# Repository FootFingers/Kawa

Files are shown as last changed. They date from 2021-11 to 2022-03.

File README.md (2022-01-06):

# Kawa-HotSwap
## A 32 key 'fixed-split' pro-micro based keyboard with a 128x64 OLED display.

Forked from CoffeeBreakKeyboards [here](https://github.com/CoffeeBreakKeyboards/kawa) and updated to use Kailh Hotswap Sockets. 

A sandwich mount case was also created based on the original Kawa PCB footprint. The central section around the OLED and controller board is covered with a sheet of acrylic, and hardware has been added to provide wireless support. 

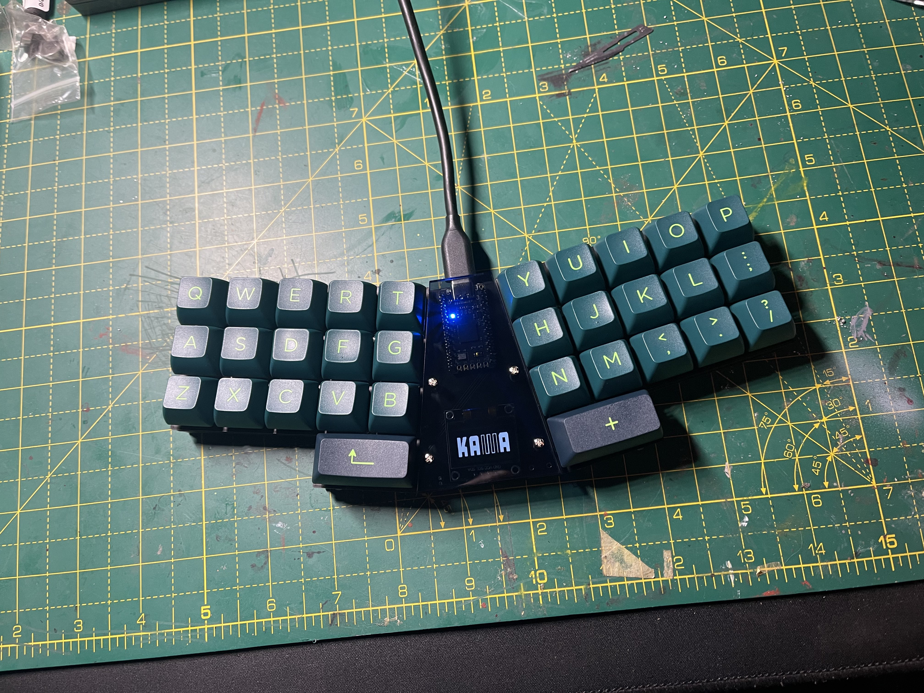
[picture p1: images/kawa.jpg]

*Pic of Kawa build courtesy of Porkus*

## Case
Plate files created:
 - Base Plate x1
 - Top Plate x2
 - Acrylic Centre Guard x1

## Firmware

Firmware files are available [here](https://github.com/sofubi/qmk_firmware/tree/kawa/rev0.1/keyboards/handwired/kawa)

Wireless firmware is still currently in development.

## Usage

Use these files at your own risk. This project is currently in development, and as such is likely to contain issues. 

## ToDo
- [ ] Wireless Firmware
- [ ] Build Guide
- [x] PCB updated to use hotswap sockets
- [x] Sandwich Mount Case + Acrylic Component Cover

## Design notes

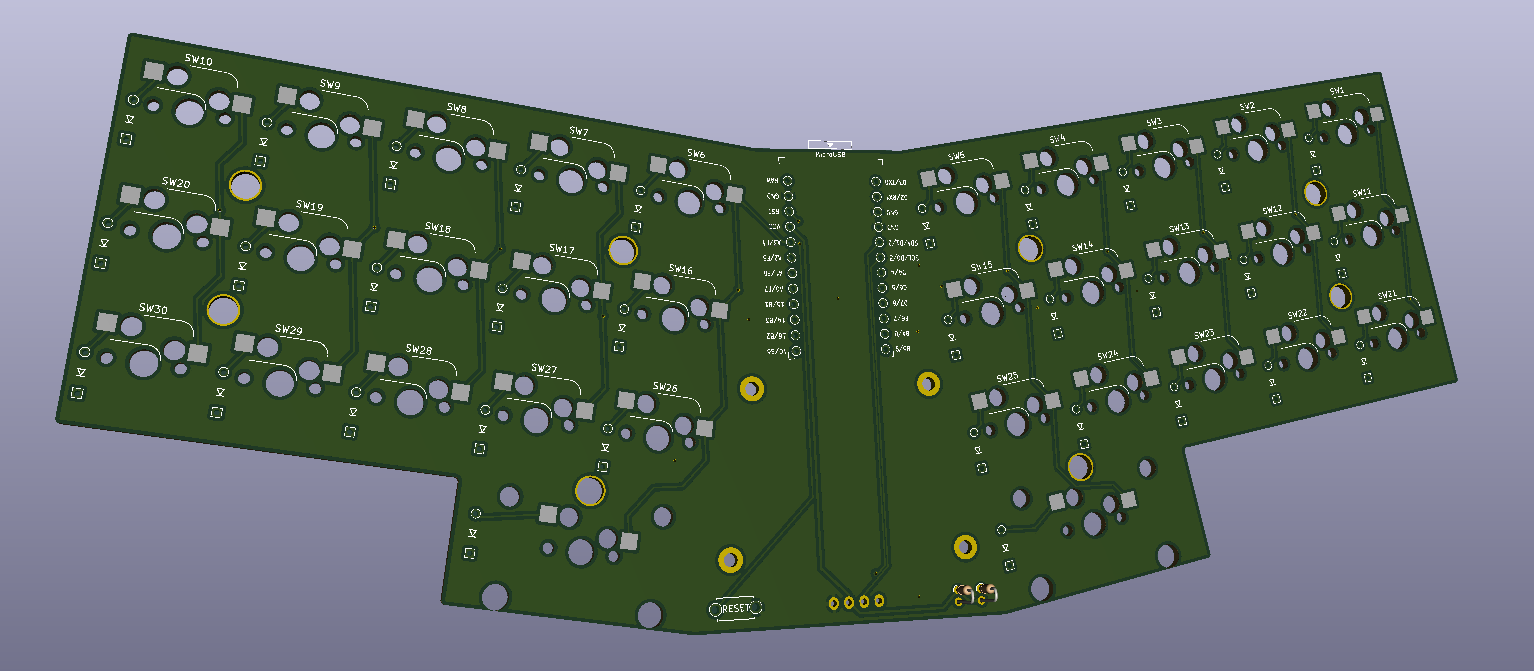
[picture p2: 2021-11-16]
images/kawaPCBbottom.PNG

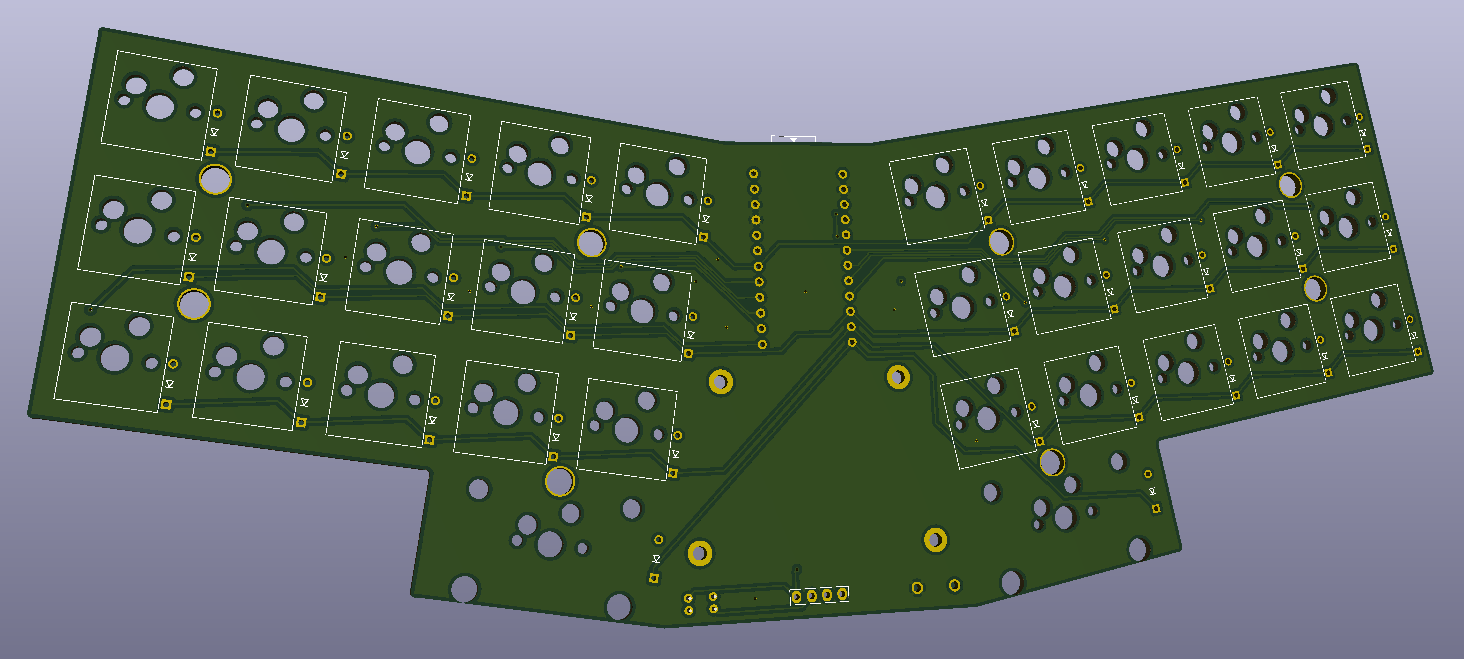
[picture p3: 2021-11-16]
images/kawaPCB.PNG

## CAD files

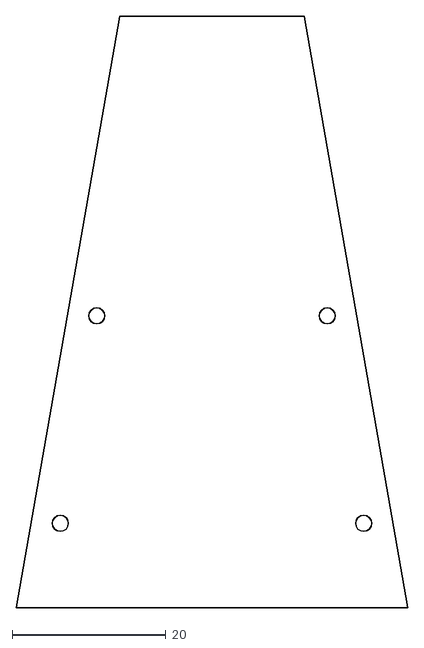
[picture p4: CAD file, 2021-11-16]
Acrylic/acrylic.dxf
51.0 x 77.0

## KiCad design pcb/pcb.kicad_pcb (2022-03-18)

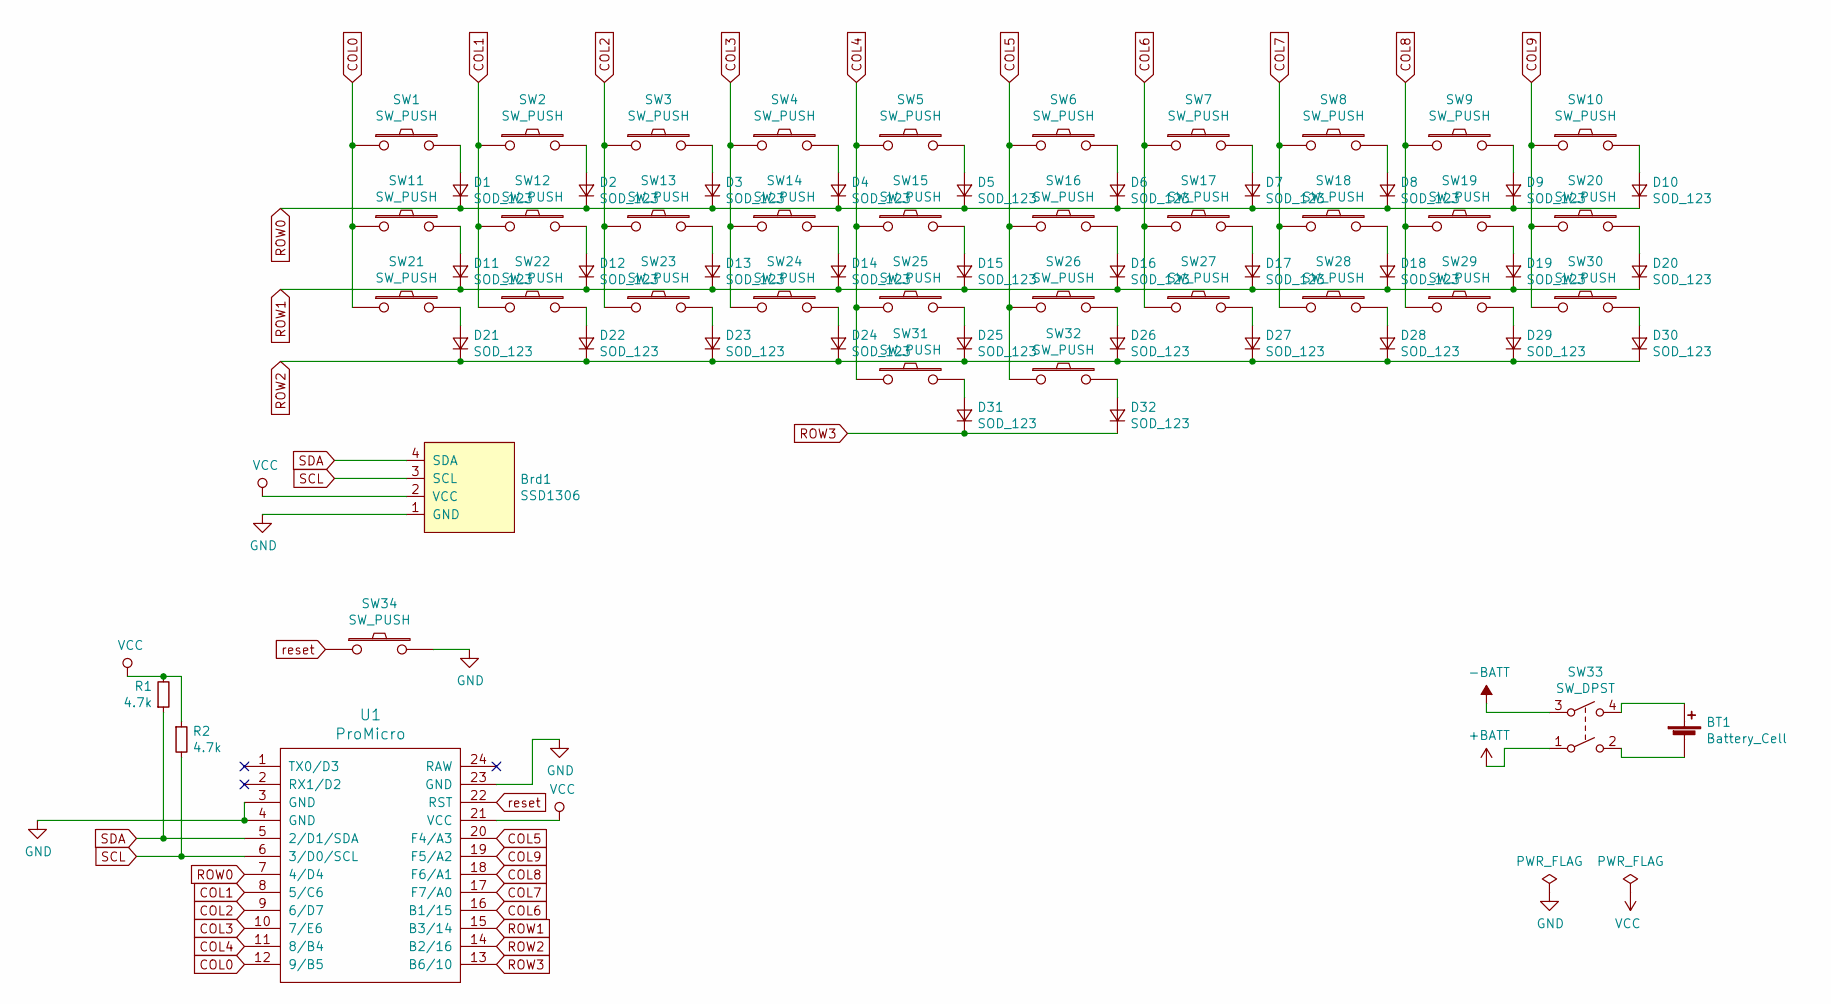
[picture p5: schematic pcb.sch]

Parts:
BT1: Battery_Cell; PinHeader_1x02_P2.00mm_Vertical
Brd1: SSD1306; 128x64OLED
D1, D2, D3, D4, D5, D6, D7, D8, D9, D10, D11, D12, D13, D14, D15, D16, D17, D18, D19, D20, D21, D22, D23, D24, D25, D26, D27, D28, D29, D30, D31, D32: SOD_123; D3_TH
R1, R2: 4.7k; R_Axial_DIN0204_L3.6mm_D1.6mm_P1.90mm_Vertical
SW1, SW2, SW3, SW4, SW5, SW6, SW7, SW8, SW9, SW10, SW11, SW12, SW13, SW14, SW15, SW16, SW17, SW18, SW19, SW20, SW21, SW22, SW23, SW24, SW25, SW26, SW27, SW28, SW29, SW30: SW_PUSH; SW_Hotswap_Kailh_1.00u
SW31, SW32: SW_PUSH; MXOnly-2U-Hotswap
SW33: SW_DPST; SW_E-Switch_EG1271_DPDT
SW34: SW_PUSH; ResetSW_1side
U1: ProMicro; ArduinoProMicro

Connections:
+BATT: SW33.1
-BATT: SW33.3
COL0: SW1.1, SW11.1, SW21.1, U1.12 (9/B5)
COL1: SW2.1, SW12.1, SW22.1, U1.8 (5/C6)
COL2: SW3.1, SW13.1, SW23.1, U1.9 (6/D7)
COL3: SW4.1, SW14.1, SW24.1, U1.10 (7/E6)
COL4: SW5.1, SW15.1, SW25.1, SW31.1, U1.11 (8/B4)
COL5: SW6.1, SW16.1, SW26.1, SW32.1, U1.20 (F4/A3)
COL6: SW7.1, SW17.1, SW27.1, U1.16 (B1/15)
COL7: SW8.1, SW18.1, SW28.1, U1.17 (F7/A0)
COL8: SW9.1, SW19.1, SW29.1, U1.18 (F6/A1)
COL9: SW10.1, SW20.1, SW30.1, U1.19 (F5/A2)
GND: Brd1.1 (GND), SW34.2, U1.3 (GND), U1.4 (GND), U1.23 (GND)
unnamed: BT1.1 (+), SW33.4
unnamed: BT1.2 (-), SW33.2
unnamed: D1.2 (A), SW1.2
unnamed: D2.2 (A), SW2.2
unnamed: D3.2 (A), SW3.2
unnamed: D4.2 (A), SW4.2
unnamed: D5.2 (A), SW5.2
unnamed: D6.2 (A), SW6.2
unnamed: D7.2 (A), SW7.2
unnamed: D8.2 (A), SW8.2
unnamed: D9.2 (A), SW9.2
unnamed: D10.2 (A), SW10.2
unnamed: D11.2 (A), SW11.2
unnamed: D12.2 (A), SW12.2
unnamed: D13.2 (A), SW13.2
unnamed: D14.2 (A), SW14.2
unnamed: D15.2 (A), SW15.2
unnamed: D16.2 (A), SW16.2
unnamed: D17.2 (A), SW17.2
unnamed: D18.2 (A), SW18.2
unnamed: D19.2 (A), SW19.2
unnamed: D20.2 (A), SW20.2
unnamed: D21.2 (A), SW21.2
unnamed: D22.2 (A), SW22.2
unnamed: D23.2 (A), SW23.2
unnamed: D24.2 (A), SW24.2
unnamed: D25.2 (A), SW25.2
unnamed: D26.2 (A), SW26.2
unnamed: D27.2 (A), SW27.2
unnamed: D28.2 (A), SW28.2
unnamed: D29.2 (A), SW29.2
unnamed: D30.2 (A), SW30.2
unnamed: D31.2 (A), SW31.2
unnamed: D32.2 (A), SW32.2
ROW0: D1.1 (K), D2.1 (K), D3.1 (K), D4.1 (K), D5.1 (K), D6.1 (K), D7.1 (K), D8.1 (K), D9.1 (K), D10.1 (K), U1.7 (4/D4)
ROW1: D11.1 (K), D12.1 (K), D13.1 (K), D14.1 (K), D15.1 (K), D16.1 (K), D17.1 (K), D18.1 (K), D19.1 (K), D20.1 (K), U1.15 (B3/14)
ROW2: D21.1 (K), D22.1 (K), D23.1 (K), D24.1 (K), D25.1 (K), D26.1 (K), D27.1 (K), D28.1 (K), D29.1 (K), D30.1 (K), U1.14 (B2/16)
ROW3: D31.1 (K), D32.1 (K), U1.13 (B6/10)
SCL: Brd1.3 (SCL), R2.2, U1.6 (3/D0/SCL)
SDA: Brd1.4 (SDA), R1.1, U1.5 (2/D1/SDA)
VCC: Brd1.2 (VCC), R1.2, R2.1, U1.21 (VCC)
reset: SW34.1, U1.22 (RST)

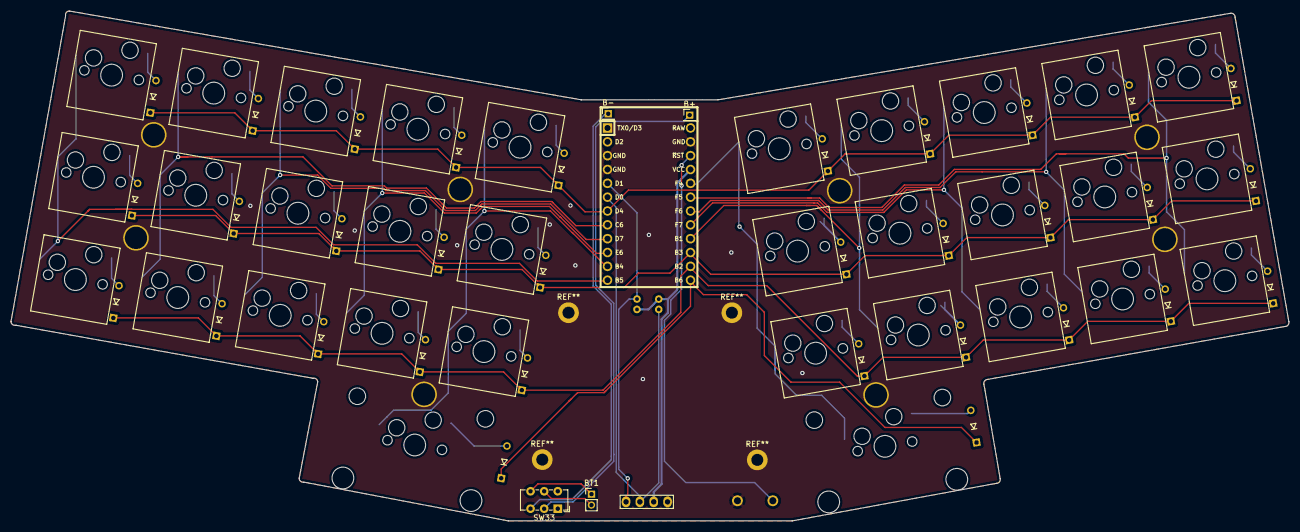
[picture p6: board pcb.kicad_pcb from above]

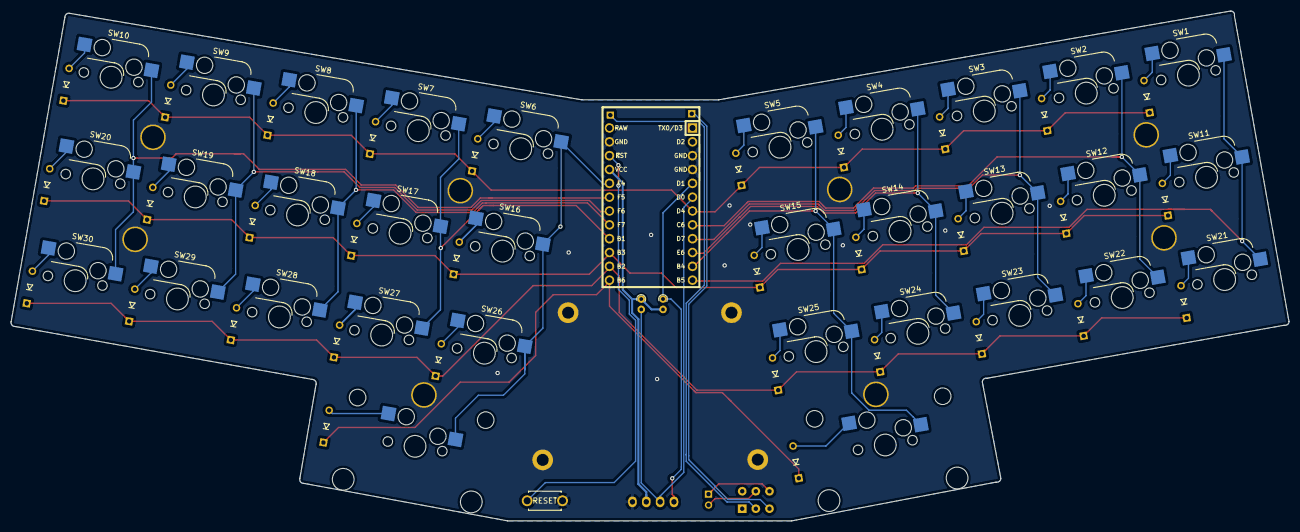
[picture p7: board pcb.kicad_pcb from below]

Board: 2 copper layers, 234.6 x 93.6 mm, 81 parts (35 on the bottom side), 53 nets.

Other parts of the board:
B+: PinHeader_1x01_P2.00mm_Vertical
B-: PinHeader_1x01_P2.00mm_Vertical
HOLE_3M, HOLE_3M#2, HOLE_3M#3, HOLE_3M#4, HOLE_3M#5, HOLE_3M#6, HOLE_3M#7, HOLE_3M#8: VAL**; HOLE_M2_TH

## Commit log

2021-12-20 fixed grounded pad + added wireless support
    Grounded pad on 'edc' column fixed.
    Additional pins for nice!nano + on/off switch for battery
2021-12-20 added wireless suport and fixed previous PCB issue
    Added additional header pins for battery usage.
    On/Off switch for battery.
    Support for wireless controller
    [PCB_TOP_PLATE.kicad_pcb, pcb.kicad_pcb, pcb.sch]
